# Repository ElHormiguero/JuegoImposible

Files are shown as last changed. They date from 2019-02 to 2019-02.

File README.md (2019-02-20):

# Metebolas
Se trata de un juego arcade cuyo objetivo es subir la bola sobre una barra para meterla en el agujero correcto del muro, en caso de no llegar a tiempo o meterla en el agujero incorrecto, la partida finaliza. Incluye 3 niveles de altura cuya dificultad va aumentando. Al colar en el tercer y último agujero, se volverá al primero reduciendo el tiempo de partida y pasando a la siguiente ronda.
El marcador muestra tanto el tiempo restante como la puntuación, la cual se va acumulando, cada vez que se acierta se añade los siguientes puntos: 50 x Agujero (1, 2 o 3) + 50 x Ronda + Tiempo restante.
El diseño incluye 4 sensores para detectar la bola, 2 finales de carrera para calibrar la posición de los motores, 2 motores paso a paso, 3 leds, 2 joysticks, un pulsador y una pantalla de 7 segmentos. Todo conectado a un único microcontrolador.
El programa se encarga de obtener la posición del joystick y traducirla en una velocidad para cada uno de los motores, controlando la posición en la que se encuentra la barra para limitar el movimiento dentro de un margen. Los sensores continuamente comprueban si la bola ha pasado por algún agujero para sumar puntos o finalizar la partida.

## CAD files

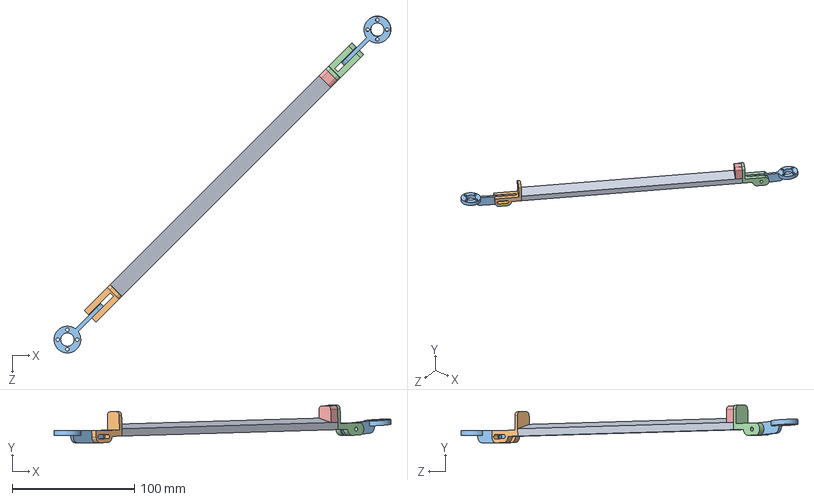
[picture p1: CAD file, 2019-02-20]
Piezas 3D/Ensamblaje1.SLDASM
275.9 x 30.9 x 275.9 mm
Barra
Articulacion2
Articulacion1_2 x 2
Articulacion2_2
Extra1

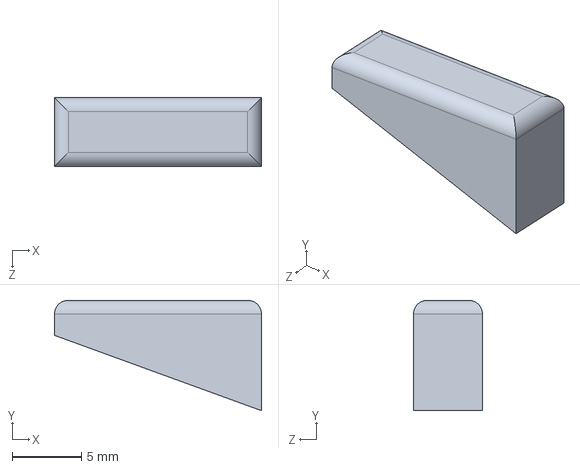
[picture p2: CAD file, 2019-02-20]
Piezas 3D/Extra2.SLDPRT
15.0 x 8.00 x 5.00 mm

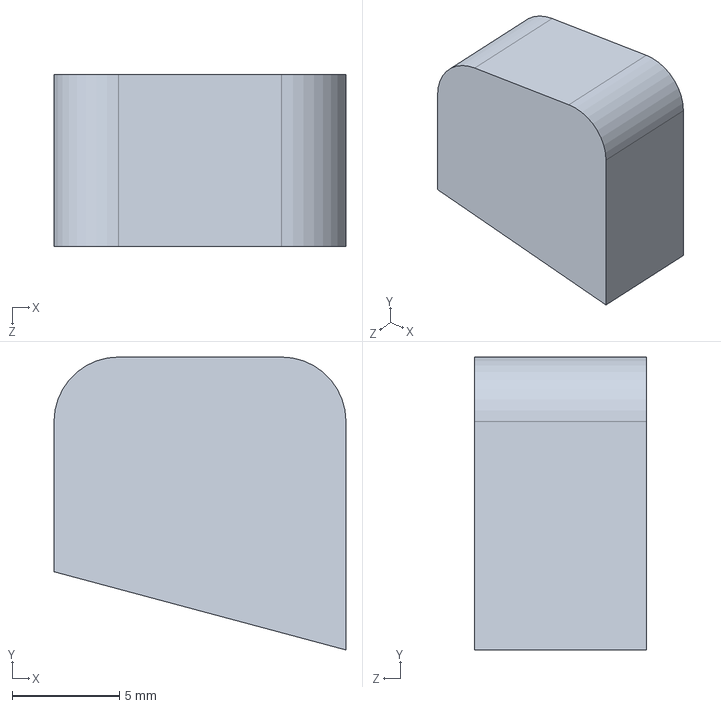
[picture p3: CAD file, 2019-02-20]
Piezas 3D/Extra1.SLDPRT
13.6 x 13.6 x 8.00 mm

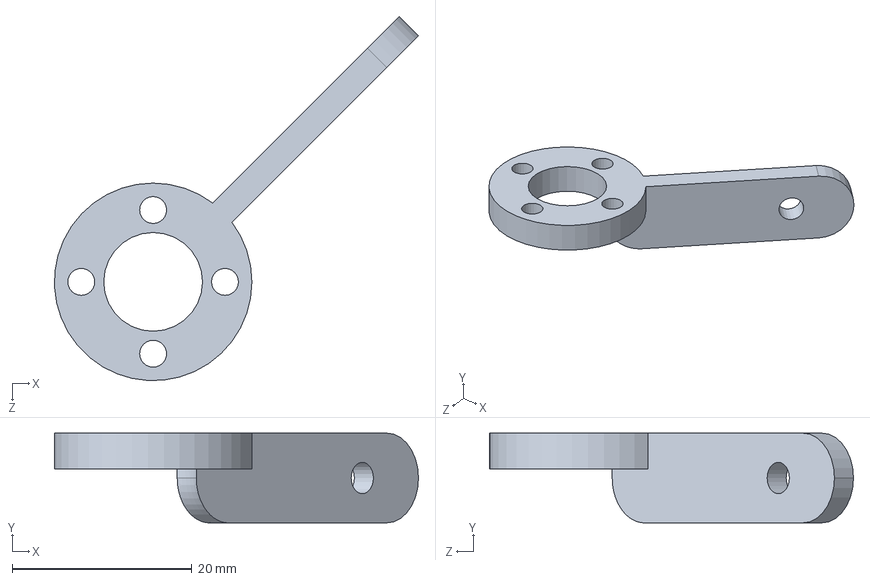
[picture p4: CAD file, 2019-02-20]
Piezas 3D/Articulacion1_2.SLDPRT
40.5 x 10.0 x 40.5 mm

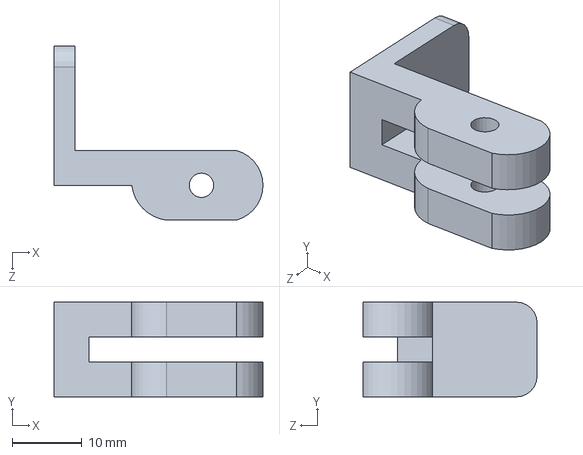
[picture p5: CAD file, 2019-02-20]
Piezas 3D/Articulacion2_2.SLDPRT
30.0 x 13.6 x 25.0 mm

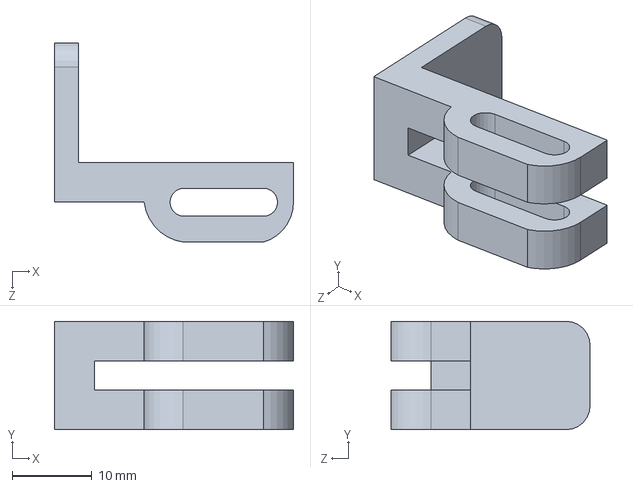
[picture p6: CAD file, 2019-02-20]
Piezas 3D/Articulacion2.SLDPRT
30.0 x 13.6 x 25.0 mm

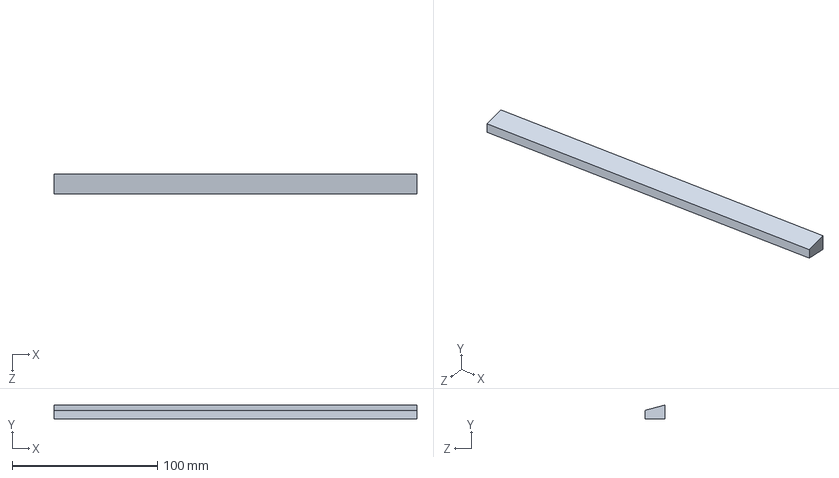
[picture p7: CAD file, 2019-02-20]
Piezas 3D/Barra.SLDPRT
250.0 x 9.62 x 13.6 mm

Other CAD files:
Piezas 3D/Articulacion1_2.STL
Piezas 3D/Articulacion2.STL
Piezas 3D/Articulacion2_2.STL
Piezas 3D/Barra.STL
Piezas 3D/Extra1.STL
Piezas 3D/Extra2.STL

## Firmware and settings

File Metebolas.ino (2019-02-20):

/*Juego arcade analógico donde el objetivo es meter la bola en el agujero correcto controlando la barra con dos joysticks. 
  Programado en Arduino Leonardo
  Autor: Javier Vargas. El Hormiguero.
  https://creativecommons.org/licenses/by/4.0/
*/
//PINES
#define PinSTEP1 8
#define PinSTEP2 5
#define PinDIR1 9
#define PinDIR2 6
#define PinFinalMotor1 A2
#define PinFinalMotor2 A3
#define PinLed1 A5
#define PinLed2 A4
#define PinLed3 4
#define PinBoton 7
#define PinInterruptor1 11
#define PinInterruptor2 10
#define PinInterruptor3 12
#define PinInterruptorFallo 13
#define PinJoystick1 A1
#define PinJoystick2 A0

//CONFIGURACION
#define Muestreo 20 //ms
//Motores
#define PasosVuelta 3200 //Pasos por vuelta del motor paso a paso
#define mmPaso 0.0025f //milimetros por paso del tornillo
#define K 0.3f //Flitro de la velocidad
#define velocidadMax 230 //rpm
#define velocidadMin 1 //rpm
#define velocidadLento 100 //rpm
#define DIRECCION1 LOW //
#define DIRECCION2 LOW //
#define distanciaMax 50 //(mm) Distancia permitida entre la rosca de ambos motores
#define alturaMax 240 //(mm) Altura maxima de los motores
#define MotorZero1 25 //Distancia que sube el motor 2 para recoger la bola
#define MotorZero2 43 //Distancia que sube para iniciar partida
#define MotorZero3 10 //Distancia por debajo de MotorZero2 que puede bajar
//Joystick
#define centro1 510 //Lectura analogica
#define max1 249 //Lectura analogica
#define min1 774 //Lectura analogica
#define centro2 511 //Lectura analogica
#define max2 261 //Lectura analogica
#define min2 761 //Lectura analogica
#define margen 5 //Margen entorno al centro 
//Partida
#define tiempoPartida 40 //Tiempo de una partida 
#define tiempoPartidaMin 10 //Tiempo minimo que puede durarar una partida
#define reduccionTiempo 10 //Reduccion de tiempo entre rondas

//LIBRERIAS Y VARIABLES

//Timer
#include <TimerOne.h>
#include <TimerThree.h>
#include <digitalWriteFast.h> //Más rapido!

//Pantalla
#include <Wire.h>
#include "Adafruit_LEDBackpack.h"
#include "Adafruit_GFX.h"
Adafruit_7segment matrix = Adafruit_7segment();

unsigned long m = 0, m2 = 0;
float rpm1, rpm2 = 0;
boolean dir1 = 1, dir2 = 1;
volatile unsigned long steps1, steps2 = 0;
byte objetivo = 0;
int tiempo = tiempoPartida;
int puntuacion = 0;
byte partida = 0;

void setup() {
  Serial.begin(115200);

  //PinMode
  pinMode(PinSTEP1, OUTPUT);
  pinMode(PinSTEP2, OUTPUT);
  pinMode(PinDIR1, OUTPUT);
  pinMode(PinDIR2, OUTPUT);
  pinMode(PinLed1, OUTPUT);
  pinMode(PinLed2, OUTPUT);
  pinMode(PinLed3, OUTPUT);
  pinMode(PinBoton, INPUT_PULLUP);
  pinMode(PinInterruptor1, INPUT_PULLUP);
  pinMode(PinInterruptor2, INPUT_PULLUP);
  pinMode(PinInterruptor3, INPUT_PULLUP);
  pinMode(PinInterruptorFallo, INPUT_PULLUP);
  pinMode(PinFinalMotor1, INPUT_PULLUP);
  pinMode(PinFinalMotor2, INPUT_PULLUP);

  //Inicio TIMER
  Timer1.initialize(250000);
  Timer1.attachInterrupt(Step1);
  Timer1.stop();

  Timer3.initialize(250000);
  Timer3.attachInterrupt(Step2);
  Timer3.stop();

  //Inicio 7 segmentos
  matrix.begin(0x70);
  Pantalla7segRayas();

  EfectoLeds();

  //Espera a pulsar el boton para empezar
  while (!Boton()) {
  }
}

////////////////////
////////LOOP////////
////////////////////

void loop() {

  //Coloca la barra en el inicio
  MotorZero();

  //Selecciona el agujero objetivo
  SeleccionarAgujero();

  //PARTIDA INICIADA!
  while (1) {
    if (m != millis() / Muestreo) {
      m = millis() / Muestreo;

      //Tiempo
      if (m2 != millis() / 1000) {
        m2 = millis() / 1000;
        tiempo--;
        Pantalla7segNumero(tiempo);
        //Fuera de tiempo
        if (tiempo == 0) {
          SetVelocidad(0, 0, 0);
          EfectoLeds();
          Pantalla7segParpadeo(puntuacion);
          //Espera a pulsar el boton
          while (!Boton()) {
          }
          //Reinicio de partida
          objetivo = 0;
          partida = 0;
          puntuacion = 0;
          tiempo = tiempoPartida;
          Pantalla7segRayas();
          return;
        }
      }

      //Velocidad obtenida con el joystick
      rpm1 = LecturaJoystick(analogRead(PinJoystick1), centro1, min1, max1, margen);
      rpm2 = LecturaJoystick(analogRead(PinJoystick2), centro2, min2, max2, margen);

      //Limita la velocidad rpm segun la posición de la tuerca
      Limites();

      //Timer de motores paso a paso
      SetVelocidad(rpm1, rpm2, 1);

      //Control de donde se cuela la bola
      switch (ControlBola()) {
        //Acierto
        case 1:
          SetVelocidad(0, 0, 0);
          Parpadeo(objetivo, 5);
          //Actualiza partida y tiempo de partida
          if (objetivo == 3) partida++;
          //Puntuacion
          Pantalla7segCuenta(puntuacion, puntuacion + objetivo * 50 + partida * 50 + tiempo);
          puntuacion += objetivo * 50 + partida * 50 + tiempo;
          Pantalla7segParpadeo(puntuacion);
          //Actualiza el tiempo de partida
          tiempo = constrain(tiempoPartida - partida * reduccionTiempo, tiempoPartidaMin, tiempoPartida);
          return;

        //Fallo
        case 2:
          SetVelocidad(0, 0, 0);
          EfectoLeds();
          Pantalla7segParpadeo(puntuacion);
          //Espera a pulsar el boton
          while (!Boton()) {
          }
          //Reinicio de partida
          objetivo = 0;
          partida = 0;
          puntuacion = 0;
          tiempo = tiempoPartida;
          Pantalla7segRayas();
          return;
      }
    }
  }
}


////////////////////
////////////////////
////////////////////

boolean Boton() {
  return !digitalRead(PinBoton);
}

void Pantalla7segNumero(int num) {
  matrix.print(num, DEC);
  matrix.writeDisplay();
  matrix.blinkRate(0);
  matrix.writeDisplay();
}

void Pantalla7segRayas() {
  matrix.print(10000, DEC);
  matrix.writeDisplay();
  matrix.blinkRate(0);
  matrix.writeDisplay();
}

void Pantalla7segBorrar() {
  matrix.clear();
  matrix.writeDisplay();
}

void Pantalla7segParpadeo(int num) {
  Pantalla7segNumero(num);
  matrix.blinkRate(2);
  matrix.writeDisplay();
}

void Pantalla7segCuenta(int num0, int num1) {
  for (int p = num0; p <= num1; p++) {
    Pantalla7segNumero(p);
    delay(5);
  }
}

byte SeleccionarAgujero() {
  //El objetivo es el agujero siguiente
  if (objetivo == 3) objetivo = 1;
  else objetivo++;
  //Enciende el led
  LedOn(objetivo);
}

byte ControlBola() {
  //Bola en agujero objetivo
  if (!digitalRead(PinInterruptor1)) {
    if (objetivo == 1) return 1;
    else return 2;
  }
  if (!digitalRead(PinInterruptor2)) {
    if (objetivo == 2) return 1;
    else return 2;
  }
  if (!digitalRead(PinInterruptor3)) {
    if (objetivo == 3) return 1;
    else return 2;
  }
  //Bola en agujero erróneo
  if (!digitalRead(PinInterruptorFallo)) return 2;
  //No hay bola detectada
  return 0;
}

void Limites() {

  //Limite por diferencia de altura entre motores
  float distancia = (float)((float)steps1 - (float)steps2) * mmPaso;
  //Motor 1 por encima de 2
  if (distancia >= distanciaMax) {
    if (rpm1 > 0) rpm1 = 0;
    if (rpm2 < 0) rpm2 = 0;
  }
  //Motor 2 por encima de 1
  if (distancia <= -distanciaMax) {
    if (rpm1 < 0) rpm1 = 0;
    if (rpm2 > 0) rpm2 = 0;
  }

  //Limite por final de recorrido superior
  if (steps1 * mmPaso >= alturaMax && rpm1 > 0) rpm1 = 0;
  if (steps2 * mmPaso >= alturaMax && rpm2 > 0) rpm2 = 0;

  //Limite por final de recorrido inferior
  if (steps1 == 0 && rpm1 < 0) rpm1 = 0;
  if (steps2 == 0 && rpm2 < 0) rpm2 = 0;
}

void MotorZero() {
  float distancia1 = 0, distancia2 = 0;
  float rpm1 = -velocidadMax;
  float rpm2 = -velocidadMax;

  //Bajamos la barra hasta dar con el final de carrera de ambos motores
  while (rpm1 != 0 || rpm2 != 0) {
    if (steps1 == 0) rpm1 = -velocidadLento;
    if (steps2 == 0) rpm2 = -velocidadLento;
    if (!digitalRead(PinFinalMotor1)) rpm1 = 0;
    if (!digitalRead(PinFinalMotor2)) rpm2 = 0;
    SetVelocidad(rpm1, rpm2, 0);
  }

  //Reinicio de la posicion 0
  steps1 = 0;
  steps2 = 0;

  //Subimos el primer motor para mover la bola
  rpm2 = velocidadMax;
  SetVelocidad(0, rpm2, 0);
  while (distancia2 < MotorZero1) {
    distancia2 = steps2 * mmPaso;
  }

  //Subimos ambos motores a la posicion cero
  rpm1 = velocidadMax;
  rpm2 = velocidadMax;
  while (rpm1 != 0 || rpm2 != 0) {
    distancia1 = steps1 * mmPaso;
    distancia2 = steps2 * mmPaso;
    if (distancia1 >= MotorZero2) rpm1 = 0;
    if (distancia2 >= MotorZero2) rpm2 = 0;
    SetVelocidad(rpm1, rpm2, 0);
  }

  //Posicion 0 a MotorZero3 mm por debajo
  steps1 = MotorZero3 / mmPaso;
  steps2 = MotorZero3 / mmPaso;
}

float LecturaJoystick(int a, int centro, int min, int max, int m) {
  float out = 0;
  if (a >= centro + m) out = map(a, centro + m, max, 0, velocidadMax);
  else if (a <= centro - m) out = map(a, centro - m, min, 0, -velocidadMax);
  return constrain(out, -velocidadMax, velocidadMax);
}

void SetVelocidad(float rpm1, float rpm2, boolean filtro) {
  static float rpm1_ant = 0;
  static float rpm2_ant = 0;

  static volatile boolean e1, e2 = 0; //Estado de los timers

  //Limite de velocidad entre los limites de velocidad maxima
  rpm1 = constrain(rpm1, -velocidadMax, velocidadMax);
  rpm2 = constrain(rpm2, -velocidadMax, velocidadMax);

  //Filtro de la velocidad para evitar cambios bruscos de aceleracion
  if (filtro) {
    rpm1 = (float)rpm1 * K + (float)rpm1_ant * (1 - K);
    rpm2 = (float)rpm2 * K + (float)rpm2_ant * (1 - K);
    rpm1_ant = rpm1;
    rpm2_ant = rpm2;
  }

  //Direccion motor 1
  if (rpm1 >= 0) {
    if (!dir1) {
      dir1 = 1;
      digitalWriteFast(PinDIR1, DIRECCION1);
    }
  }
  else if (dir1) {
    dir1 = 0;
    digitalWriteFast(PinDIR1, !DIRECCION1);
  }

  //Direccion motor 2
  if (rpm2 >= 0) {
    if (!dir2) {
      dir2 = 1;
      digitalWriteFast(PinDIR2, DIRECCION2);
    }
  }
  else if (dir2) {
    dir2 = 0;
    digitalWriteFast(PinDIR2, !DIRECCION2);
  }

  //Velocidad motor 1
  if (abs(rpm1) >= velocidadMin) {
    unsigned long T1 = 30000000 / (PasosVuelta * abs(rpm1));
    if (!e1) { //Inicia el timer
      Timer1.start();
      //digitalWriteFast(PinENABLE1, LOW); //Activa el motor
      e1 = 1;
    }
    Timer1.setPeriod(T1); //Periodo de la interrpucion
  }
  else if (e1) { //Desactiva el timer
    Timer1.stop();
    //digitalWriteFast(PinENABLE1, HIGH); //Desactiva el motor
    e1 = 0;
  }

  //Velocidad motor 2
  if (abs(rpm2) >= velocidadMin) {
    unsigned long T2 = 30000000 / (PasosVuelta * abs(rpm2));
    if (!e2) {  //Inicia el timer
      Timer3.start();
      //digitalWriteFast(PinENABLE2, LOW); //Activa el motor
      e2 = 1;
    }
    Timer3.setPeriod(T2); //Periodo de la interrpucion
  }
  else if (e2) { //Desactiva el timer
    Timer3.stop();
    //digitalWriteFast(PinENABLE2, HIGH); //Desactiva el motor
    e2 = 0;
  }

}

//STEP
void Step1() {
  static volatile boolean e = 0;
  if (e) {
    digitalWriteFast(PinSTEP1, LOW);
    e = 0;
  }
  else {
    digitalWriteFast(PinSTEP1, HIGH);
    e = 1;
    if (dir1) steps1++;
    else if (steps1 > 0) steps1--;
  }
}
void Step2() {
  static volatile boolean e = 0;
  if (e) {
    digitalWriteFast(PinSTEP2, LOW);
    e = 0;
  }
  else {
    digitalWriteFast(PinSTEP2, HIGH);
    e = 1;
    if (dir2) steps2++;
    else if (steps2 > 0) steps2--;
  }
}

void LedOn(int led) {
  switch (led) {
    case 0:
      digitalWrite(PinLed1, LOW);
      digitalWrite(PinLed2, LOW);
      digitalWrite(PinLed3, LOW);
      break;
    case 1:
      digitalWrite(PinLed1, HIGH);
      digitalWrite(PinLed2, LOW);
      digitalWrite(PinLed3, LOW);
      break;
    case 2:
      digitalWrite(PinLed1, LOW);
      digitalWrite(PinLed2, HIGH);
      digitalWrite(PinLed3, LOW);
      break;
    case 3:
      digitalWrite(PinLed1, LOW);
      digitalWrite(PinLed2, LOW);
      digitalWrite(PinLed3, HIGH);
      break;
  }
}

void Parpadeo(byte led, byte n) {
  for (byte i = 0; i < n; i++) {
    LedOn(led);
    delay(100);
    LedOn(0);
    delay(100);
  }
}

void EfectoLeds() {
  for (byte i = 0; i < 5; i++) {
    for (byte led = 1; led <= 3; led++) {
      LedOn(led);
      delay(100);
    }
  }
  LedOn(0);
}
